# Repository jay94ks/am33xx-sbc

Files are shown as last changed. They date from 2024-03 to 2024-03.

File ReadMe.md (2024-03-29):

# AM33xx SBC project.
This project is to create a SBC (Single board computer).
However, despite its name, it is divided into several boards.

## Power-supply board.
  This take power from Type-C USB, and regulates it to 3.3v, 1.8v, 1.5v and 1.1v LDO.
and `STM32G030F6P6` controls power sequence of each voltage lines. And, unfortunately, 
current implementation has no `On/Off` button. when the power cable attached, 
this just turn the board on.

### Rendering:
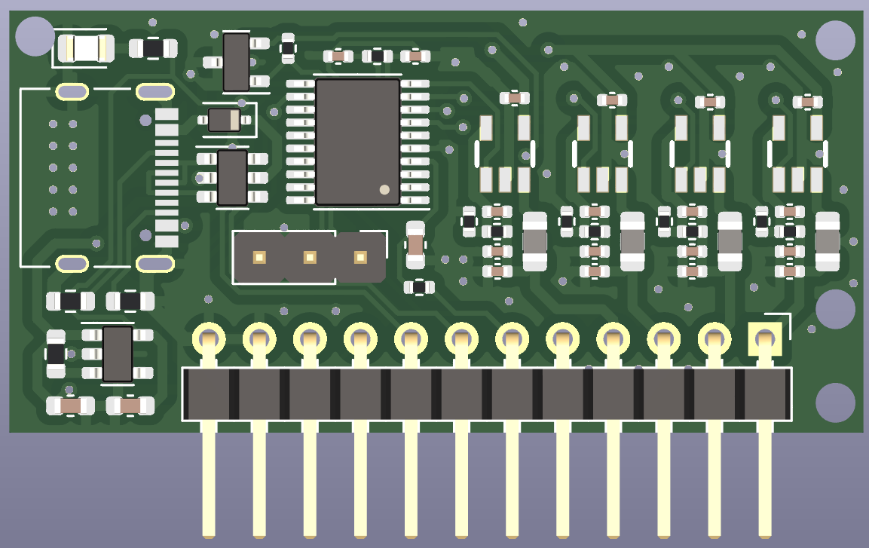
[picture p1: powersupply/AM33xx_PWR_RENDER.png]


### Schematic:
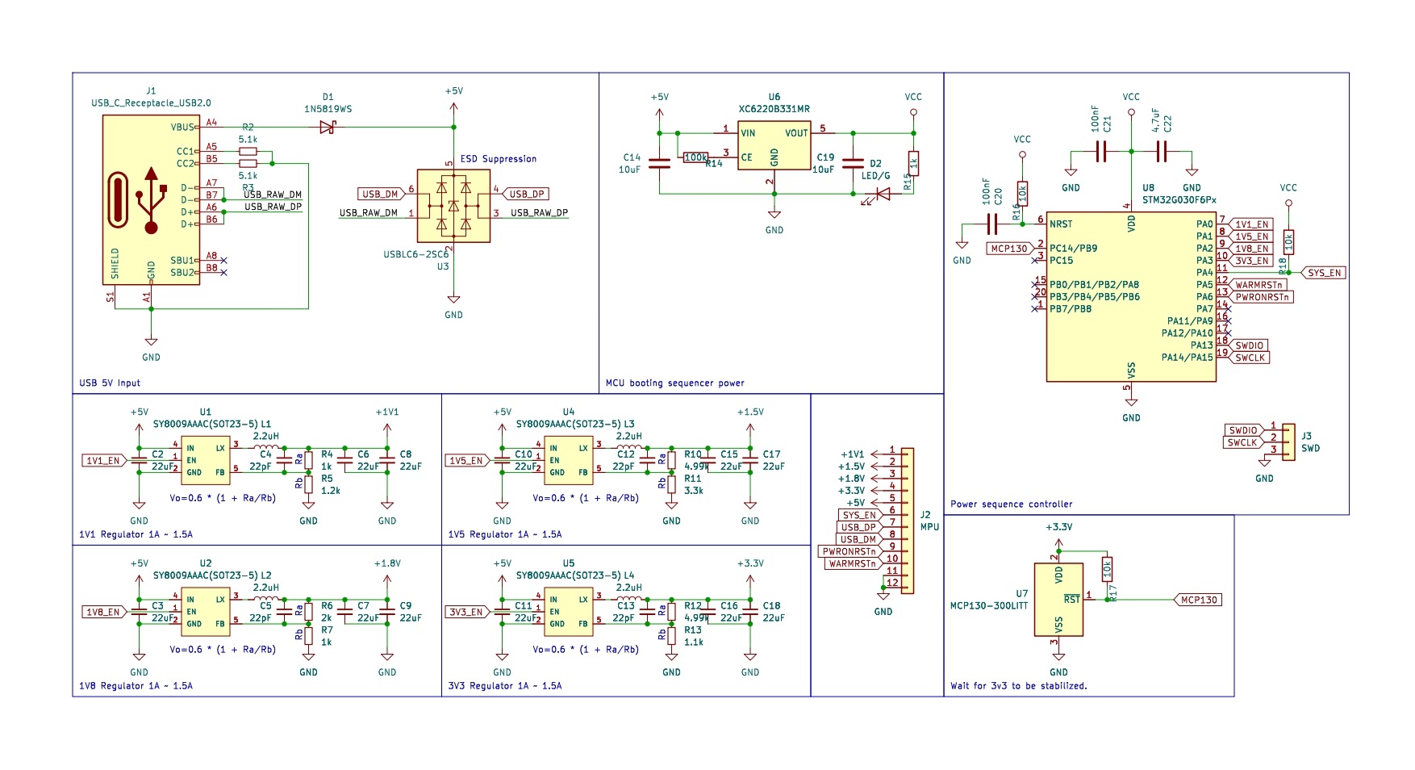
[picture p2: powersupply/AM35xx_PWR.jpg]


### Pinmap.
Pins of the mini power-supply board has following pin map (2.54mm pitch):

```
Right to left order.
1. 1v1
2. 1v5
3. 1v8
4. 3v3
5. 5v
6. SYS_EN
7. USB_DP
8. USB_DM
9. PWRONRSTn
10. WARMRSTn
11. GND
12. GND
```

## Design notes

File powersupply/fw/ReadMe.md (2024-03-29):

### Power sequence controller firmware
WIP.

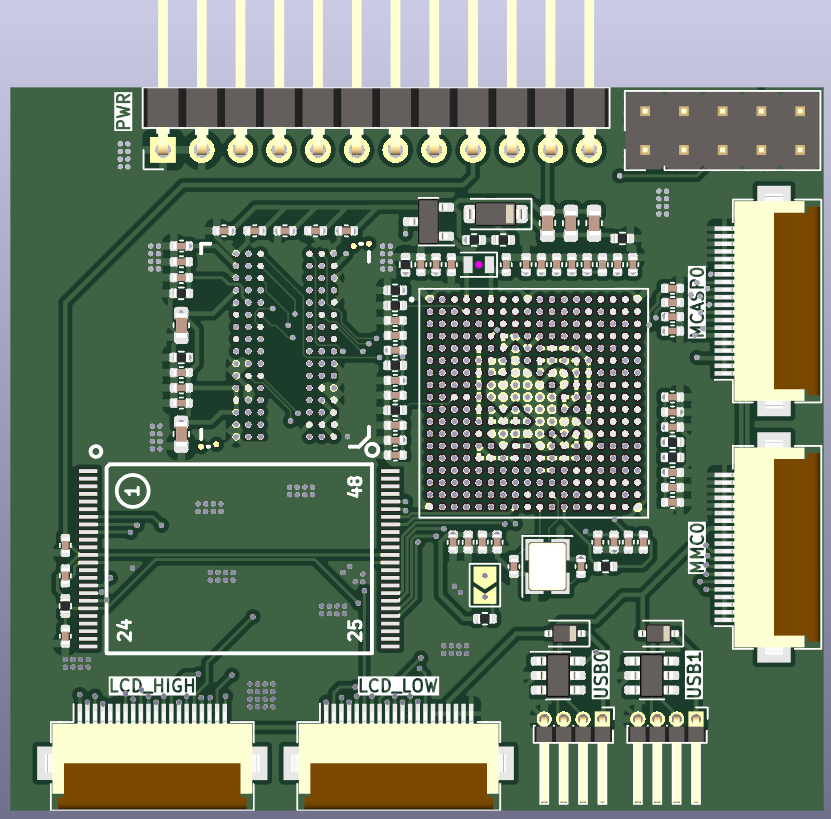
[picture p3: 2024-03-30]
coreboard/AM33xx_CORE-RDR.png

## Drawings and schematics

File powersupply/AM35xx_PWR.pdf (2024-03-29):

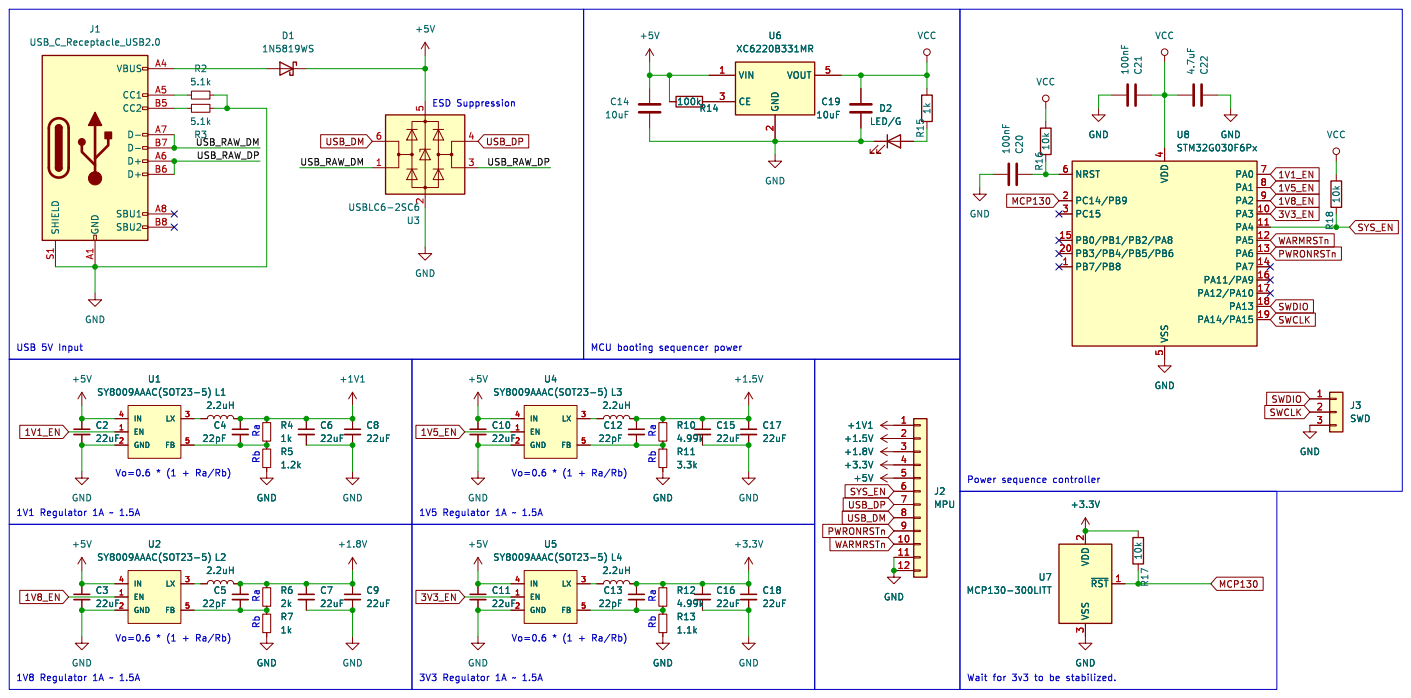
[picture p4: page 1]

2 CE 3 VOUT 5 U6 XC6220B331MR GND GND

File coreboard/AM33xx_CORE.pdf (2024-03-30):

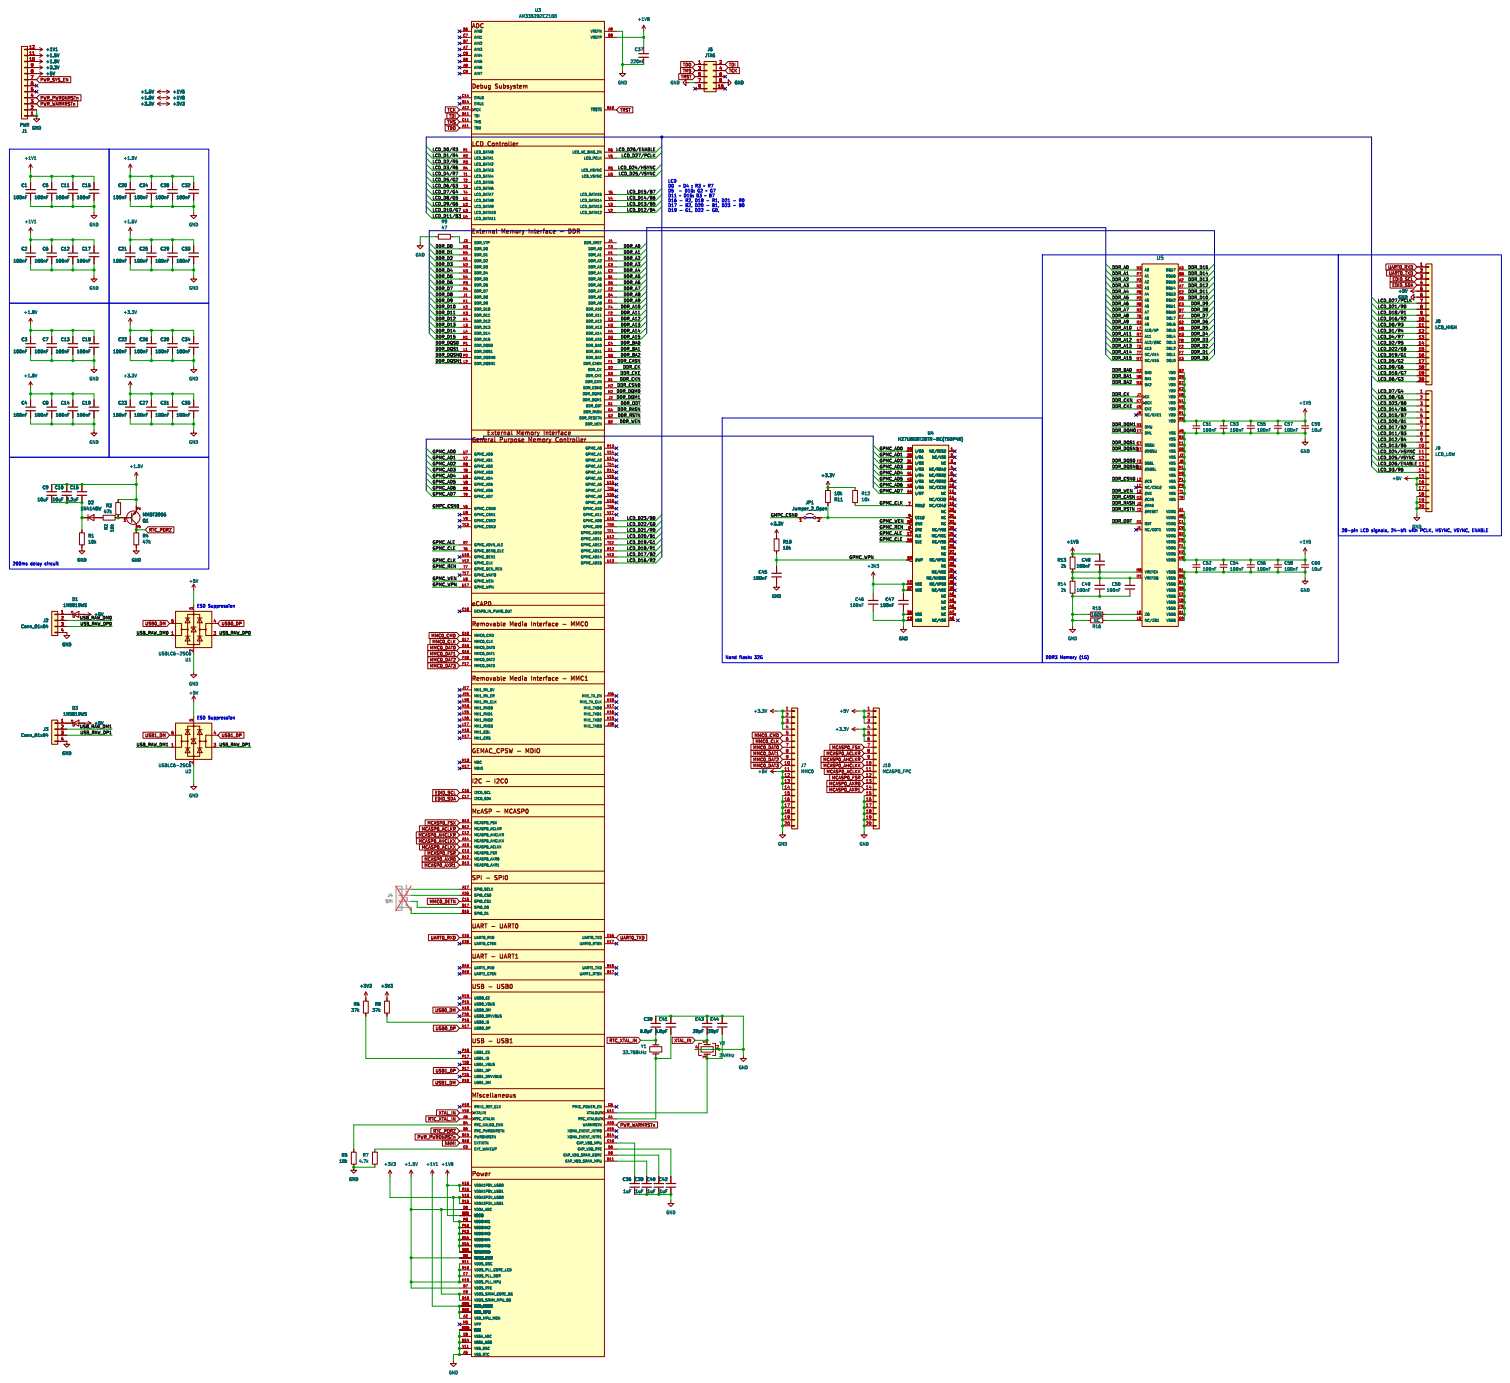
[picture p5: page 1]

ESD Suppression

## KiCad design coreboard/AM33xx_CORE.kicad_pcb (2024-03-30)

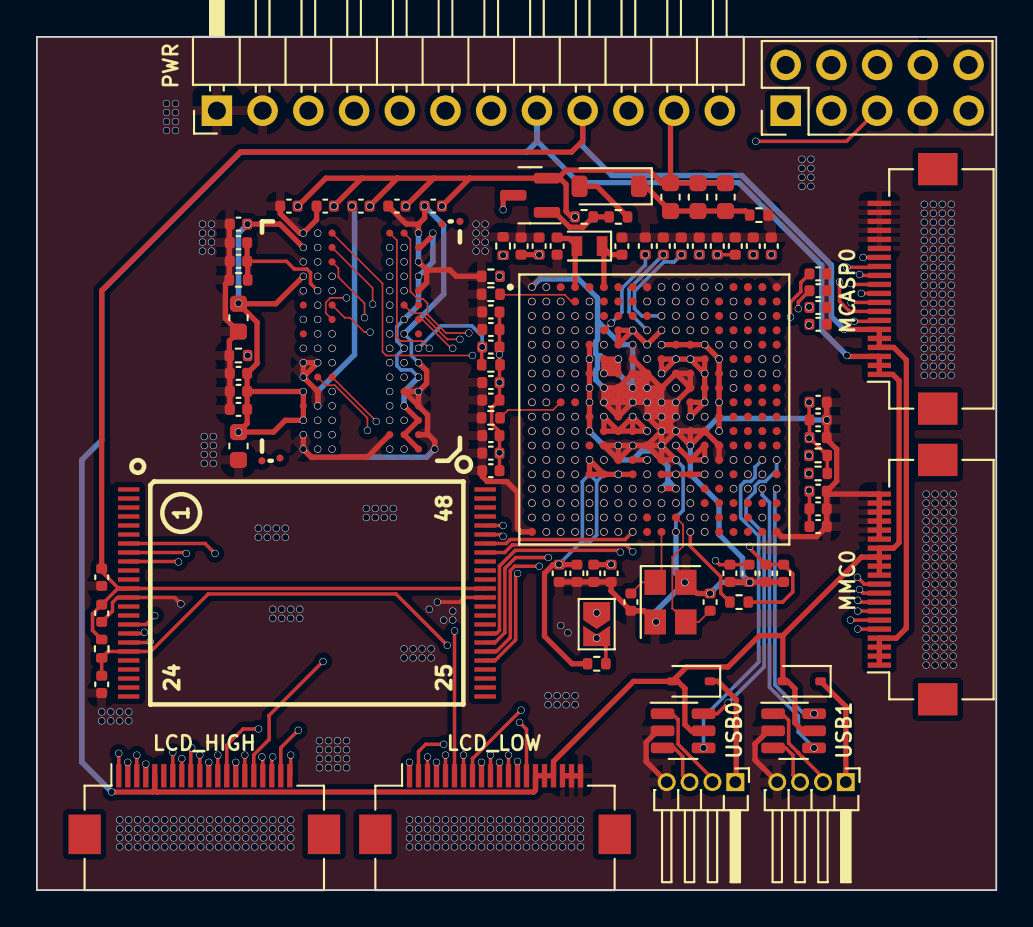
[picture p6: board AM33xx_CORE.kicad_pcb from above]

Board: 8 copper layers, 53.3 x 47.4 mm, 94 parts (0 on the bottom side), 154 nets.

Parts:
C1, C2, C3, C4, C5, C6, C7, C8, C11, C12, C13, C14, C16, C17, C18, C19, C20, C21, C22, C23, C24, C25, C26, C27, C28, C29, C30, C31, C32, C33, C34, C35, C45, C46, C47, C48, C49, C50, C51, C52, C53, C54, C55, C56, C57, C58: 100nF; C_0402_1005Metric
C9, C10, C59, C60: 10uF; C_0603_1608Metric
C15: 2.2uF; C_0603_1608Metric
C36, C38, C40, C42: 1uF; C_0402_1005Metric
C39, C41: 6.8pF; C_0402_1005Metric
C43, C44: 28pF; C_0402_1005Metric
D1, D3: 1N5819WS; D_SOD-323
D2: 1N4148W; D_SOD-123
J1: PWR; PinHeader_1x12_P2.54mm_Horizontal
J2, J3: Conn_01x04; PinHeader_1x04_P1.27mm_Horizontal
J6: JTAG; PinHeader_2x05_P2.54mm_Vertical
J7: MMC0; Hirose_FH12-20S-0.5SH_1x20-1MP_P0.50mm_Horizontal
J8: LCD_HIGH; Hirose_FH12-20S-0.5SH_1x20-1MP_P0.50mm_Horizontal
J9: LCD_LOW; Hirose_FH12-20S-0.5SH_1x20-1MP_P0.50mm_Horizontal
J10: MCASP0_FPC; Hirose_FH12-20S-0.5SH_1x20-1MP_P0.50mm_Horizontal
JP1: Jumper_2_Open; SolderJumper-2_P1.3mm_Open_TrianglePad1.0x1.5mm
Q1: MMBT3906; SOT-23
R1, R2, R5, R10, R11, R12: 10k; R_0402_1005Metric
R3, R4: 47k; R_0402_1005Metric
R6, R8: 37k; R_0402_1005Metric
R7: 4.7k; R_0402_1005Metric
R9: 47; R_0402_1005Metric
R13, R14: 2k; R_0402_1005Metric
R15: 160k; R_0402_1005Metric
U1, U2: USBLC6-2SC6; SOT-23-6
U3: AM3352BZCZ100; BGA324CP80_18X18_1500X1500X140B50N
U4: H27UBG8T2BTR-BC(TSOP48); TSOP48
U5: H5TQ2G63BFR_MEM4G16D3EABG-125--H5TC8G63AMR-PBA_K4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; FBGA96(HYNIX_SAMSUNG_512MX16_DDR3)
Y1: 32.768kHz; Crystal_SMD_2012-2Pin_2.0x1.2mm
Y2: 24MHz; Crystal_SMD_3225-4Pin_3.2x2.5mm

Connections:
+1.5V: C9.1, C10.1, C15.1, C20.1, C21.1, C24.1, C25.1, C28.1, C29.1, C32.1, C33.1, C48.1, C51.1, C52.1, C53.1, C54.1, C55.1, C56.1, C57.1, C58.1, C59.1, C60.1, J1.11, Q1.2 (E), R3.1, R13.1, U3.D7 (VDDS_RTC), U3.D8 (VDDA_ADC), U3.D10 (VDDS_SRAM_MPU_BB), U3.E5 (VDDS_DDR), U3.E7 (VDDS_PLL_DDR), U3.E9 (VDDS_SRAM_CORE_BG), U3.F5 (VDDS_DDR), U3.G5 (VDDS_DDR), U3.H5 (VDDS_DDR), U3.H15 (VDDS_PLL_MPU), U3.J5 (VDDS_DDR), U3.K5 (VDDS_DDR), U3.L5 (VDDS_DDR), U3.R10 (VDDS_PLL_CORE_LCD), U3.R11 (VDDS_OSC), U5.A1 (VDDQ), U5.A8 (VDDQ), U5.B2 (VDD), U5.C1 (VDDQ), U5.C9 (VDDQ), U5.D2 (VDDQ), U5.D9 (VDD), U5.E9 (VDDQ), U5.F1 (VDDQ), U5.G7 (VDD), U5.H2 (VDDQ), U5.H9 (VDDQ), U5.K2 (VDD), U5.K8 (VDD), U5.N1 (VDD), U5.N9 (VDD), U5.R1 (VDD), U5.R9 (VDD)
+1V1: C1.1, C2.1, C5.1, C6.1, C11.1, C12.1, C16.1, C17.1, J1.12, U3.A2 (VDD_MPU_MON), U3.F6 (VDD_CORE), U3.F7 (VDD_CORE), U3.F10 (VDD_MPU), U3.F11 (VDD_MPU), U3.F12 (VDD_MPU), U3.F13 (VDD_MPU), U3.G6 (VDD_CORE), U3.G7 (VDD_CORE), U3.G10 (VDD_CORE), U3.G13 (VDD_MPU), U3.H11 (VDD_CORE), U3.H13 (VDD_MPU), U3.J12 (VDD_CORE), U3.J13 (VDD_MPU), U3.K6 (VDD_CORE), U3.K8 (VDD_CORE), U3.K12 (VDD_CORE), U3.L6 (VDD_CORE), U3.L7 (VDD_CORE), U3.L8 (VDD_CORE), U3.L9 (VDD_CORE), U3.M11 (VDD_CORE), U3.M13 (VDD_CORE), U3.N8 (VDD_CORE), U3.N9 (VDD_CORE), U3.N12 (VDD_CORE), U3.N13 (VDD_CORE)
+1V8: C3.1, C4.1, C7.1, C8.1, C13.1, C14.1, C18.1, C19.1, J1.10, U3.B9 (VREFP), U3.E6 (VDDS), U3.E14 (VDDS), U3.F9 (VDDS), U3.K13 (VDDS), U3.N6 (VDDS), U3.N16 (VDDA1P8V_USB0), U3.P9 (VDDS), U3.P14 (VDDS), U3.R16 (VDDA1P8V_USB1)
+3V3: C22.1, C23.1, C26.1, C27.1, C30.1, C31.1, C34.1, C35.1, C46.1, C47.1, J1.9, J7.1, J7.2, J7.3, J7.4, J10.4, J10.5, J10.6, R6.1, R8.1, R10.1, R11.2, R12.1, U3.E10 (VDDSHV6), U3.E11 (VDDSHV6), U3.E12 (VDDSHV6), U3.E13 (VDDSHV6), U3.F14 (VDDSHV6), U3.G14 (VDDSHV6), U3.H14 (VDDSHV4), U3.J14 (VDDSHV4), U3.K14 (VDDSHV5), U3.L14 (VDDSHV5), U3.N5 (VDDSHV6), U3.N15 (VDDA3P3V_USB0), U3.P5 (VDDSHV6), U3.P6 (VDDSHV6), U3.P7 (VDDSHV1), U3.P8 (VDDSHV1), U3.P10 (VDDSHV2), U3.P11 (VDDSHV2), U3.P12 (VDDSHV3), U3.P13 (VDDSHV3), U3.R15 (VDDA3P3V_USB1), U4.12 (VCC), U4.37 (VCC)
+5V: D1.2 (A), D3.2 (A), J1.8, J7.11, J7.12, J7.13, J7.14, J8.5, J9.15, J9.16, J9.17, J10.1, J10.2, J10.3, U1.5 (VBUS), U2.5 (VBUS)
/DDR_A0: U3.F3 (DDR_A0), U5.N3 (A0)
/DDR_A1: U3.H1 (DDR_A1), U5.P7 (A1)
/DDR_A2: U3.E4 (DDR_A2), U5.P3 (A2)
/DDR_A3: U3.C3 (DDR_A3), U5.N2 (A3)
/DDR_A4: U3.C2 (DDR_A4), U5.P8 (A4)
/DDR_A5: U3.B1 (DDR_A5), U5.P2 (A5)
/DDR_A6: U3.D5 (DDR_A6), U5.R8 (A6)
/DDR_A7: U3.E2 (DDR_A7), U5.R2 (A7)
/DDR_A8: U3.D4 (DDR_A8), U5.T8 (A8)
/DDR_A9: U3.C1 (DDR_A9), U5.R3 (A9)
/DDR_A10: U3.F4 (DDR_A10), U5.L7 (A10/AP)
/DDR_A11: U3.F2 (DDR_A11), U5.R7 (A11)
/DDR_A12: U3.E3 (DDR_A12), U5.N7 (A12/#BC)
/DDR_A13: U3.H3 (DDR_A13), U5.T3 (A13)
/DDR_A14: U3.H4 (DDR_A14), U5.T7 (NC/A14)
/DDR_A15: U3.D3 (DDR_A15), U5.M7 (NC/A15)
/DDR_BA0: U3.C4 (DDR_BA0), U5.M2 (BA0)
/DDR_BA1: U3.E1 (DDR_BA1), U5.N8 (BA1)
/DDR_BA2: U3.B3 (DDR_BA2), U5.M3 (BA2)
/DDR_CASN: U3.F1 (DDR_CASN), U5.K3 (#CAS)
/DDR_CK: U3.D2 (DDR_CK), U5.J7 (CK)
/DDR_CKE: U3.G3 (DDR_CKE), U5.K9 (CKE)
/DDR_CKN: U3.D1 (DDR_CKN), U5.K7 (#CK)
/DDR_CSN0: U3.H2 (DDR_CSN0), U5.L2 (#CS)
/DDR_D0: U3.M3 (DDR_D0), U5.E3 (DQL0)
/DDR_D1: U3.M4 (DDR_D1), U5.F7 (DQL1)
/DDR_D2: U3.N1 (DDR_D2), U5.F2 (DQL2)
/DDR_D3: U3.N2 (DDR_D3), U5.F8 (DQL3)
/DDR_D4: U3.N3 (DDR_D4), U5.H3 (DQL4)
/DDR_D5: U3.N4 (DDR_D5), U5.H8 (DQL5)
/DDR_D6: U3.P3 (DDR_D6), U5.G2 (DQL6)
/DDR_D7: U3.P4 (DDR_D7), U5.H7 (DQL7)
/DDR_D8: U3.J1 (DDR_D8), U5.D7 (DQU0)
/DDR_D9: U3.K1 (DDR_D9), U5.C3 (DQU1)
/DDR_D10: U3.K2 (DDR_D10), U5.C8 (DQU2)
/DDR_D11: U3.K3 (DDR_D11), U5.C2 (DQU3)
/DDR_D12: U3.K4 (DDR_D12), U5.A7 (DQU4)
/DDR_D13: U3.L3 (DDR_D13), U5.A2 (DQU5)
/DDR_D14: U3.L4 (DDR_D14), U5.B8 (DQU6)
/DDR_D15: U3.M1 (DDR_D15), U5.A3 (DQU7)
/DDR_DQM0: U3.M2 (DDR_DQM0), U5.E7 (DML)
/DDR_DQM1: U3.J2 (DDR_DQM1), U5.D3 (DMU)
/DDR_DQS0: U3.P1 (DDR_DQS0), U5.F3 (DQSL)
/DDR_DQS1: U3.L1 (DDR_DQS1), U5.C7 (DQSU)
/DDR_DQSN0: U3.P2 (DDR_DQSN0), U5.G3 (#DQSL)
/DDR_DQSN1: U3.L2 (DDR_DQSN1), U5.B7 (#DQSU)
/DDR_ODT: U3.G1 (DDR_ODT), U5.K1 (ODT)
/DDR_RASN: U3.G4 (DDR_RASN), U5.J3 (#RAS)
/DDR_RSTN: U3.G2 (DDR_RESETN), U5.T2 (#RESET)
/DDR_WEN: U3.B2 (DDR_WEN), U5.L3 (#WE)
/GMPC_CSN0: JP1.1 (A), U3.V6 (GPMC_CSN0)
/GPMC_AD0: U3.U7 (GPMC_AD0), U4.29 (I/O0)
/GPMC_AD1: U3.V7 (GPMC_AD1), U4.30 (I/O1)
/GPMC_AD2: U3.R8 (GPMC_AD2), U4.31 (I/O2)
/GPMC_AD3: U3.T8 (GPMC_AD3), U4.32 (I/O3)
/GPMC_AD4: U3.U8 (GPMC_AD4), U4.41 (I/O4)
/GPMC_AD5: U3.V8 (GPMC_AD5), U4.42 (I/O5)
/GPMC_AD6: U3.R9 (GPMC_AD6), U4.43 (I/O6)
/GPMC_AD7: U3.T9 (GPMC_AD7), U4.44 (I/O7)
/GPMC_ALE: U3.R7 (GPMC_ADVN_ALE), U4.17 (ALE)
/GPMC_CLE: U3.T6 (GPMC_BEN0_CLE), U4.16 (CLE)
/GPMC_CLK: R12.2, U3.V12 (GPMC_CLK), U4.7 (RB1#)
/GPMC_REN: U3.T7 (GPMC_OEN_REN), U4.8 (#RE)
/GPMC_WEN: U3.U6 (GPMC_WEN), U4.18 (#WE)
/GPMC_WPN: C45.1, R10.2, U3.U17 (GPMC_WPN), U4.19 (#WP)
/LCD_D0/R3: J8.11, U3.R1 (LCD_DATA0)
/LCD_D1/R4: J8.12, U3.R2 (LCD_DATA1)
/LCD_D2/R5: J8.14, U3.R3 (LCD_DATA2)
/LCD_D3/R6: J9.14, U3.R4 (LCD_DATA3)
/LCD_D4/R7: J8.13, U3.T1 (LCD_DATA4)
/LCD_D5/G2: J8.17, U3.T2 (LCD_DATA5)
/LCD_D6/G3: J8.20, U3.T3 (LCD_DATA6)
/LCD_D7/G4: J9.1, U3.T4 (LCD_DATA7)
/LCD_D8/G5: J9.2, U3.U1 (LCD_DATA8)
/LCD_D9/G6: J8.18, U3.U2 (LCD_DATA9)
/LCD_D10/G7: J8.19, U3.U3 (LCD_DATA10)
/LCD_D11/B3: J9.8, U3.U4 (LCD_DATA11)
/LCD_D12/B4: J9.9, U3.V2 (LCD_DATA12)
/LCD_D13/B5: J9.10, U3.V3 (LCD_DATA13)
/LCD_D14/B6: J9.4, U3.V4 (LCD_DATA14)
/LCD_D15/B7: J9.5, U3.T5 (LCD_DATA15)
/LCD_D16/R2: J8.10, U3.U13 (GPMC_AD15)
/LCD_D17/B2: J9.7, U3.V13 (GPMC_AD14)
/LCD_D18/R1: J8.9, U3.R12 (GPMC_AD13)
/LCD_D19/G1: J8.16, U3.T12 (GPMC_AD12)
/LCD_D20/B1: J9.6, U3.U12 (GPMC_AD11)
/LCD_D21/R0: J8.8, U3.T11 (GPMC_AD10)
/LCD_D22/G0: J8.15, U3.T10 (GPMC_AD9)
/LCD_D23/B0: J9.3, U3.U10 (GPMC_AD8)
/LCD_D24/HSYNC: J9.11, U3.R5 (LCD_HSYNC)
/LCD_D25/VSYNC: J9.12, U3.U5 (LCD_VSYNC)
/LCD_D26/ENABLE: J9.13, U3.R6 (LCD_AC_BIAS_EN)
/LCD_D27/PCLK: J8.7, U3.V5 (LCD_PCLK)
/USB_RAW_DM0: J2.2, U1.1 (I/O1)
/USB_RAW_DM1: J3.2, U2.1 (I/O1)
/USB_RAW_DP0: J2.3, U1.3 (I/O2)
/USB_RAW_DP1: J3.3, U2.3 (I/O2)
EDID_SCL: J8.3, U3.C16 (I2C0_SCL)
EDID_SDA: J8.4, U3.C17 (I2C0_SDA)
GND: C1.2, C2.2, C3.2, C4.2, C5.2, C6.2, C7.2, C8.2, C11.2, C12.2, C13.2, C14.2, C16.2, C17.2, C18.2, C19.2, C20.2, C21.2, C22.2, C23.2, C24.2, C25.2, C26.2, C27.2, C28.2, C29.2, C30.2, C31.2, C32.2, C33.2, C34.2, C35.2, C36.2, C38.2, C39.1, C40.2, C41.1, C42.2, C43.1, C44.1, C45.2, C46.2, C47.2, C49.2, C50.2, C51.2, C52.2, C53.2, C54.2, C55.2, C56.2, C57.2, C58.2, C59.2, C60.2, J1.1, J1.2, J2.4, J3.4, J6.7, J6.8, J7.15, J7.16, J7.17, J7.18, J7.19, J7.20, J8.6, J9.18, J9.19, J9.20, J10.15, J10.16, J10.17, J10.18, J10.19, J10.20, R1.2, R4.2, R5.2, R7.2, R9.1, R14.2, R15.2, U1.2 (GND), U2.2 (GND), U3.A1 (VSS), U3.A5 (VSS_RTC), U3.A9 (VREFN), U3.A18 (VSS), U3.E8 (VSSA_ADC), U3.F8 (VSS), U3.G8 (VSS), U3.G9 (VSS), U3.G11 (VSS), U3.G12 (VSS), U3.H6 (VSS), U3.H7 (VSS), U3.H8 (VSS), U3.H9 (VSS), U3.H10 (VSS), U3.H12 (VSS), U3.J6 (VSS), U3.J7 (VSS), U3.J8 (VSS), U3.J9 (VSS), U3.J10 (VSS), U3.J11 (VSS), U3.K7 (VSS), U3.K9 (VSS), U3.K10 (VSS), U3.K11 (VSS), U3.L10 (VSS), U3.L11 (VSS), U3.L12 (VSS), U3.L13 (VSS), U3.M6 (VSS), U3.M7 (VSS), U3.M8 (VSS), U3.M9 (VSS), U3.M10 (VSS), U3.M12 (VSS), U3.M14 (VSSA_USB), U3.N7 (VSS), U3.N10 (VSS), U3.N11 (VSS), U3.N14 (VSSA_USB), U3.V1 (VSS), U3.V11 (VSS_OSC), U3.V18 (VSS), U4.13 (VSS), U4.36 (VSS), U5.A9 (VSS), U5.B1 (VSSQ), U5.B3 (VSS), U5.B9 (VSSQ), U5.D1 (VSSQ), U5.D8 (VSSQ), U5.E1 (VSS), U5.E2 (VSSQ), U5.E8 (VSSQ), U5.F9 (VSSQ), U5.G1 (VSSQ), U5.G8 (VSS), U5.G9 (VSSQ), U5.J2 (VSS), U5.J8 (VSS), U5.M1 (VSS), U5.M9 (VSS), U5.P1 (VSS), U5.P9 (VSS), U5.T1 (VSS), U5.T9 (VSS), Y2.2, Y2.4
MCASP0_ACLKR: J10.8, U3.B12 (MCASP0_ACLKR)
MCASP0_ACLKX: J10.11, U3.A13 (MCASP0_ACLKX)
MCASP0_AHCLKR: J10.9, U3.C12 (MCASP0_AHCLKR)
MCASP0_AHCLKX: J10.10, U3.A14 (MCASP0_AHCLKX)
MCASP0_AXR0: J10.13, U3.D12 (MCASP0_AXR0)
MCASP0_AXR1: J10.14, U3.D13 (MCASP0_AXR1)
MCASP0_FSR: J10.12, U3.C13 (MCASP0_FSR)
MCASP0_FSX: J10.7, U3.B13 (MCASP0_FSX)
MMC0_CLK: J7.6, U3.G17 (MMC0_CLK)
MMC0_CMD: J7.5, U3.G18 (MMC0_CMD)
MMC0_DAT0: J7.7, U3.G16 (MMC0_DAT0)
MMC0_DAT1: J7.8, U3.G15 (MMC0_DAT1)
MMC0_DAT2: J7.9, U3.F18 (MMC0_DAT2)
MMC0_DAT3: J7.10, U3.F17 (MMC0_DAT3)
unnamed: D1.1 (K), J2.1
unnamed: D2.2 (A), R2.1
unnamed: C9.2, C10.2, C15.2, D2.1 (K), R1.1
unnamed: D3.1 (K), J3.1
unnamed: JP1.2 (B), R11.1, U4.9 (CE1#)
unnamed: Q1.1 (B), R2.2, R3.2
unnamed: C36.1, U3.C10 (CAP_VBB_MPU)
unnamed: C42.1, U3.D6 (CAP_VDD_RTC)
unnamed: C40.1, U3.D9 (CAP_VDD_SRAM_CORE)
unnamed: C38.1, U3.D11 (CAP_VDD_SRAM_MPU)
unnamed: R9.2, U3.J3 (DDR_VTP)
unnamed: R7.1, U3.C5 (EXT_WAKEUP)
unnamed: R5.1, U3.B4 (RTC_KALDO_ENN)
unnamed: C41.2, U3.A4 (RTC_XTALOUT), Y1.2
unnamed: R8.2, U3.P16 (USB0_ID)
unnamed: R6.2, U3.P17 (USB1_ID)
unnamed: C44.2, U3.U11 (XTALOUT), Y2.3
unnamed: C48.2, C49.1, C50.1, R13.2, R14.1, U5.H1 (VREFDQ), U5.M8 (VREFCA)
unnamed: R15.1, U5.L8 (ZQ)
PWR_PWRONRSTn: J1.4, U3.B15 (PWRONRSTN)
PWR_WARMRSTn: J1.3, U3.A10 (WARMRSTN)
RTC_PORZ: Q1.3 (C), R4.1, U3.B5 (RTC_PWRONRSTN)
RTC_XTAL_IN: C39.2, U3.A6 (RTC_XTALIN), Y1.1
TCK: J6.4, U3.A12 (TCK)
TDI: J6.2, U3.B11 (TDI)
TDO: J6.1, U3.A11 (TDO)
TMS: J6.3, U3.C11 (TMS)
TRST: J6.5, U3.B10 (~TRSTN)
UART0_RXD: J8.1, U3.E15 (UART0_RXD)
UART0_TXD: J8.2, U3.E16 (UART0_TXD)
USB0_DM: U1.6 (I/O1), U3.N18 (USB0_DM)
USB0_DP: U1.4 (I/O2), U3.N17 (USB0_DP)
USB1_DM: U2.6 (I/O1), U3.R18 (USB1_DM)
USB1_DP: U2.4 (I/O2), U3.R17 (USB1_DP)
XTAL_IN: C43.2, U3.V10 (XTALIN), Y2.1

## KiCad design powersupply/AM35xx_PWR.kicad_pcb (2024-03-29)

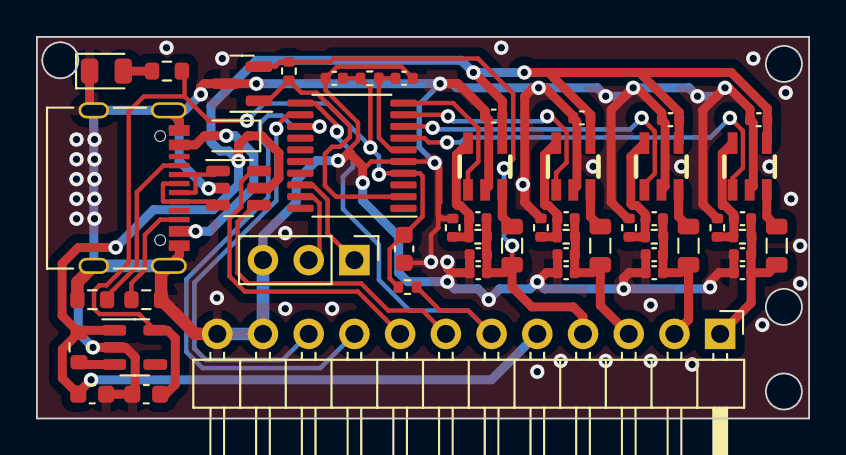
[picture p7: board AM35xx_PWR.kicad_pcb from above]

Board: 2 copper layers, 42.9 x 21.2 mm, 53 parts (0 on the bottom side), 35 nets.

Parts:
C2, C3, C6, C7, C8, C9, C10, C11, C15, C16, C17, C18: 22uF; C_0402_1005Metric
C4, C5, C12, C13: 22pF; C_0402_1005Metric
C14, C19: 10uF; C_0603_1608Metric
C20, C21: 100nF; C_0402_1005Metric
C22: 4.7uF; C_0603_1608Metric
D1: 1N5819WS; D_SOD-323
D2: LED/G; LED_0805_2012Metric
J1: USB_C_Receptacle_USB2.0; USB_C_Receptacle_Palconn_UTC16-G
J2: MPU; PinHeader_1x12_P2.54mm_Horizontal
J3: SWD; PinHeader_1x03_P2.54mm_Vertical
L1, L2, L3, L4: 2.2uH; L_0805_2012Metric
R2, R3: 5.1k; R_0603_1608Metric
R4, R7: 1k; R_0402_1005Metric
R5: 1.2k; R_0402_1005Metric
R6: 2k; R_0402_1005Metric
R10, R12: 4.99k; R_0402_1005Metric
R11: 3.3k; R_0402_1005Metric
R13: 1.1k; R_0402_1005Metric
R14: 100k; R_0603_1608Metric
R15: 1k; R_0603_1608Metric
R16, R17, R18: 10k; R_0402_1005Metric
U1, U2, U4, U5: SY8009AAAC(SOT23-5); SOT-23-5
U3: USBLC6-2SC6; SOT-23-6
U6: XC6220B331MR; SOT-23-5
U7: MCP130-300LITT; SOT-23
U8: STM32G030F6Px; TSSOP-20_4.4x6.5mm_P0.65mm

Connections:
1V1_EN: U1.1 (EN), U8.7 (PA0)
1V5_EN: U4.1 (EN), U8.8 (PA1)
1V8_EN: U2.1 (EN), U8.9 (PA2)
3V3_EN: U5.1 (EN), U8.10 (PA3)
+1.5V: C12.1, C15.1, C17.1, J2.2, L3.2, R10.1
+1V1: C4.1, C6.1, C8.1, J2.1, L1.2, R4.1
+1V8: C5.1, C7.1, C9.1, J2.3, L2.2, R6.1
+3V3: C13.1, C16.1, C18.1, J2.4, L4.2, R12.1, R17.2, U7.2 (VDD)
+5V: C2.1, C3.1, C10.1, C11.1, C14.1, D1.1 (K), J2.5, R14.2, U1.4 (IN), U2.4 (IN), U3.5 (VBUS), U4.4 (IN), U5.4 (IN), U6.1 (VIN)
/USB_RAW_DM: J1.A7 (D-), J1.B7 (D-), U3.1 (I/O1)
/USB_RAW_DP: J1.A6 (D+), J1.B6 (D+), U3.3 (I/O2)
GND: C2.2, C3.2, C6.2, C7.2, C8.2, C9.2, C10.2, C11.2, C14.2, C15.2, C16.2, C17.2, C18.2, C19.2, C20.2, C21.2, C22.1, D2.1 (K), J1.A1 (GND), J1.A12 (GND), J1.B1 (GND), J1.B12 (GND), J1.S1 (SHIELD), J2.11, J2.12, J3.3, R2.2, R3.2, R5.2, R7.2, R11.2, R13.2, U1.2 (GND), U2.2 (GND), U3.2 (GND), U4.2 (GND), U5.2 (GND), U6.2 (GND), U7.3 (VSS), U8.5 (VSS)
MCP130: R17.1, U7.1 (~RST), U8.2 (PC14/PB9)
unnamed: D1.2 (A), J1.A4 (VBUS), J1.A9 (VBUS), J1.B4 (VBUS), J1.B9 (VBUS)
unnamed: D2.2 (A), R15.1
unnamed: J1.A5 (CC1), R2.1
unnamed: J1.B5 (CC2), R3.1
unnamed: C4.2, R4.2, R5.1, U1.5 (FB)
unnamed: L1.1, U1.3 (LX)
unnamed: C5.2, R6.2, R7.1, U2.5 (FB)
unnamed: L2.1, U2.3 (LX)
unnamed: C12.2, R10.2, R11.1, U4.5 (FB)
unnamed: L3.1, U4.3 (LX)
unnamed: C13.2, R12.2, R13.1, U5.5 (FB)
unnamed: L4.1, U5.3 (LX)
unnamed: R14.1, U6.3 (CE)
unnamed: C20.1, R16.1, U8.6 (NRST)
PWRONRSTn: J2.9, U8.13 (PA6)
SWCLK: J3.2, U8.19 (PA14/PA15)
SWDIO: J3.1, U8.18 (PA13)
SYS_EN: J2.6, R18.1, U8.11 (PA4)
USB_DM: J2.8, U3.6 (I/O1)
USB_DP: J2.7, U3.4 (I/O2)
VCC: C19.1, C21.1, C22.2, R15.2, R16.2, R18.2, U6.5 (VOUT), U8.4 (VDD)
WARMRSTn: J2.10, U8.12 (PA5)

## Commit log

2024-03-29 Initial commit.
    [AM35xx_PWR.kicad_pcb, AM35xx_PWR.kicad_sch]
2024-03-30 Core board
    [AM33xx_CORE.kicad_pcb, AM33xx_CORE.kicad_sch]
